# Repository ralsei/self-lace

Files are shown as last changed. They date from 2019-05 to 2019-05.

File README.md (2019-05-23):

# Self-lacing Shoe

My final project for Swartzendruber's Digital Electronics class in 2019, built w/ Skillet (https://github.com/killerskyman).
It's a shoe that ties itself.

## Render

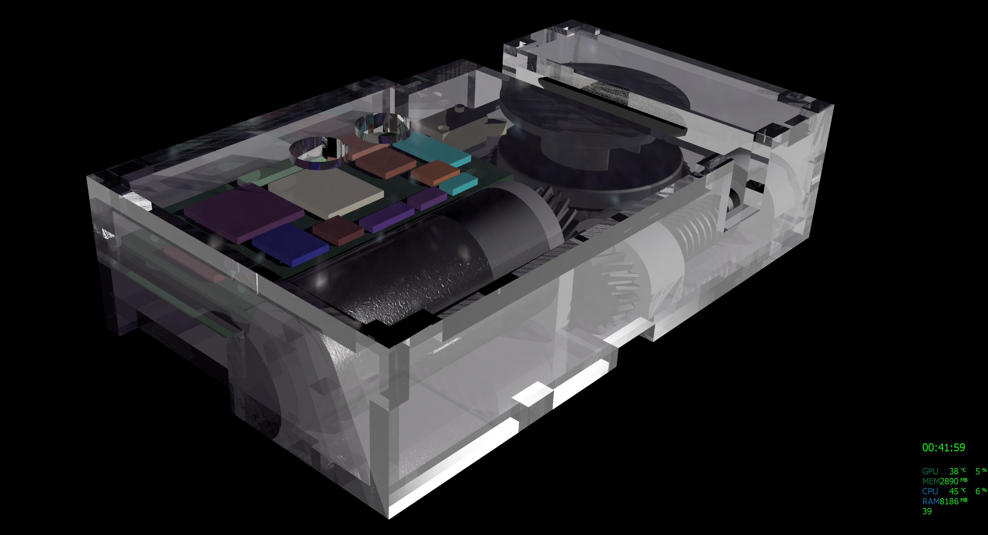
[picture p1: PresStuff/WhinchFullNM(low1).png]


## Licensing

It's under the BSD license with an additional clause stating that you can't use this for PLTW.

## Building

The CAD is made in Inventor, and the PCB is made in EAGLE.
To build the code, you must make the PCB as specified, bootload it, then upload code via FTDI.

Use the script `build` with the following parameters:

`./build main.ino <your TTY here>`

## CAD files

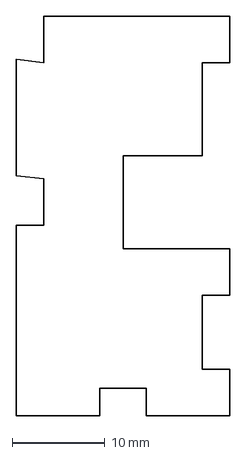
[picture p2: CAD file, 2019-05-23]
CAD/ShoeWinch/Laser/lefttopnm.dxf
23.0 x 43.0 mm

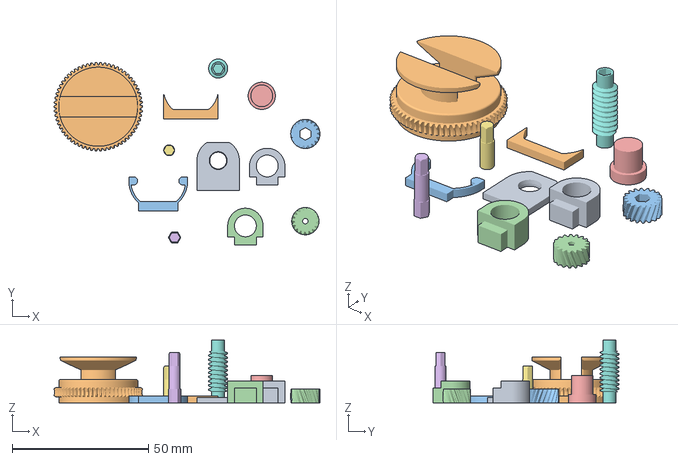
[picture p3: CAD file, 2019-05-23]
CAD/ShoeWinch/printer/Basecomp_Solid3_3.3mf
97.6 x 68.2 x 23.0 mm

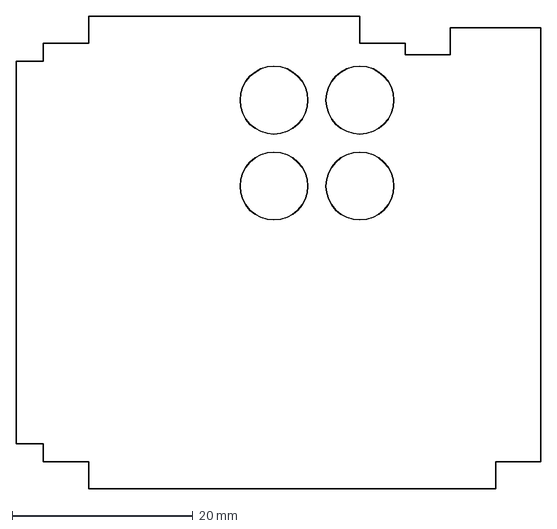
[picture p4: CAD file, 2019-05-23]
CAD/ShoeWinch/Laser/top.dxf
58.0 x 52.3 mm

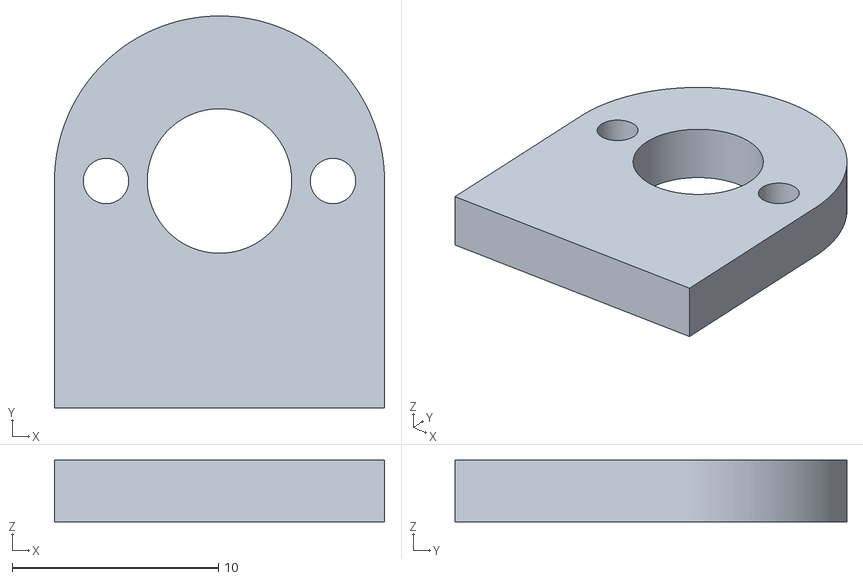
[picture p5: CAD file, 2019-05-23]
CAD/ShoeWinch/printer/PartsNM_MotorHolderNM_4.stl
16.0 x 19.0 x 3.00

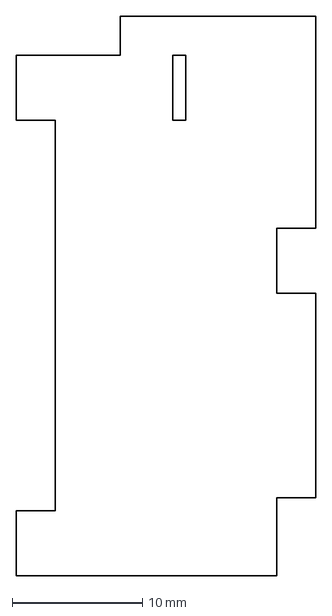
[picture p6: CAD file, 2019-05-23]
CAD/ShoeWinch/Laser/leftbot.dxf
23.1 x 43.0 mm

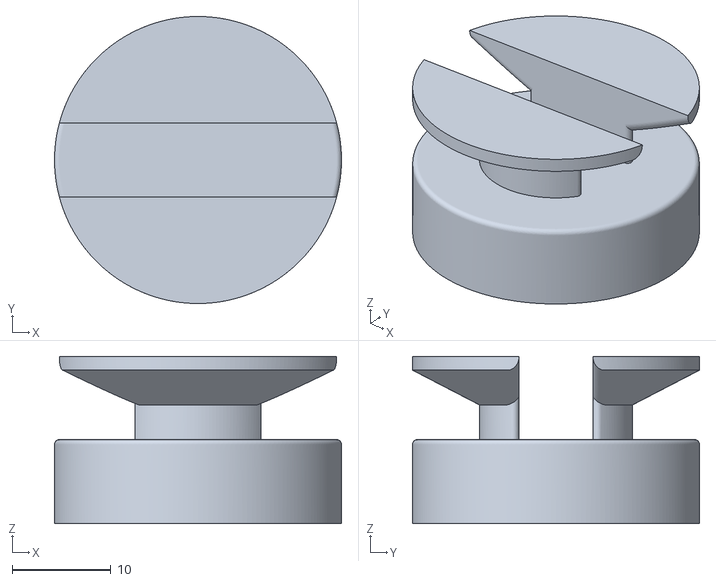
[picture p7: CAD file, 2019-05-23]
CAD/ShoeWinch/printer/WinchNM.stl
29.0 x 29.0 x 16.9

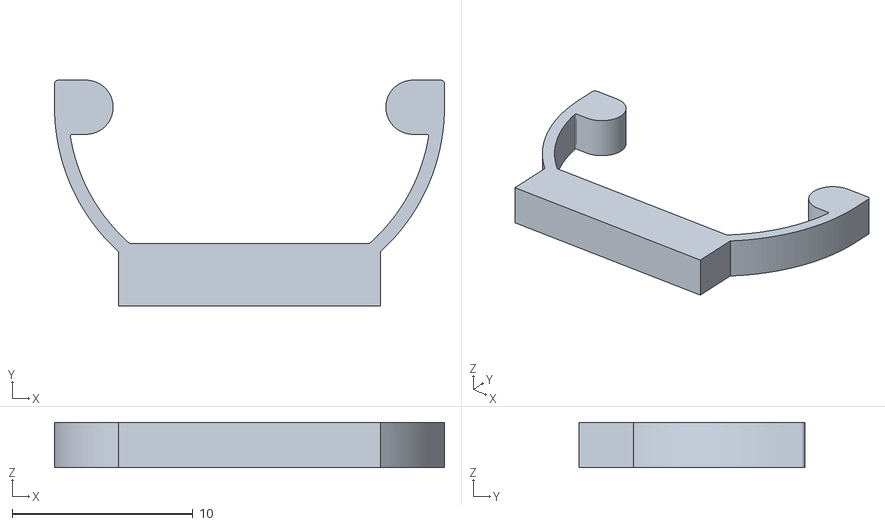
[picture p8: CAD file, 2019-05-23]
CAD/ShoeWinch/printer/Basecomp_Solid5_5.stl
21.6 x 12.5 x 2.50

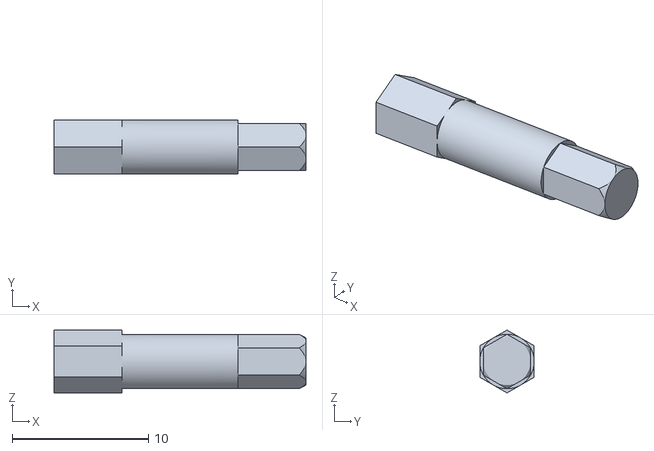
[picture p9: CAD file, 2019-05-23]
CAD/ShoeWinch/printer/Shaft2.stl
18.5 x 4.00 x 4.62

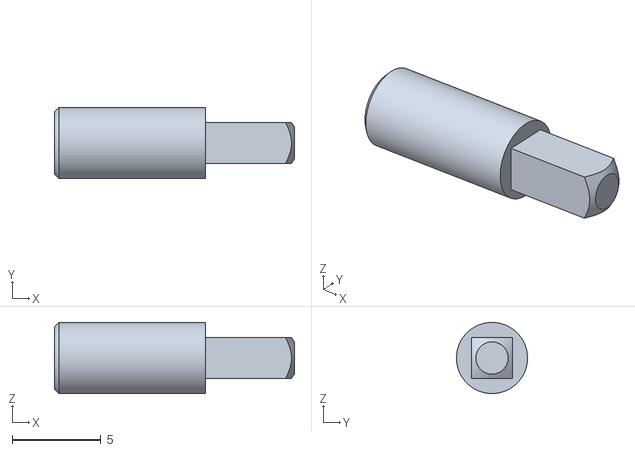
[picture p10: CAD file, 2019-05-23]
CAD/ShoeWinch/printer/Shaft3_2.stl
13.5 x 4.00 x 4.00

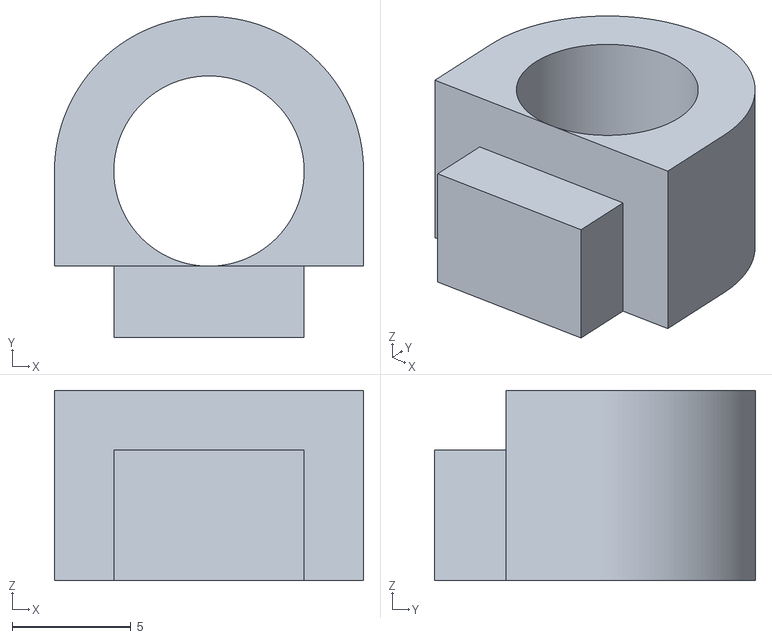
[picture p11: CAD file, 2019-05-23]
CAD/ShoeWinch/printer/Basecomp_Solid1_1.stl
13.0 x 13.5 x 8.00

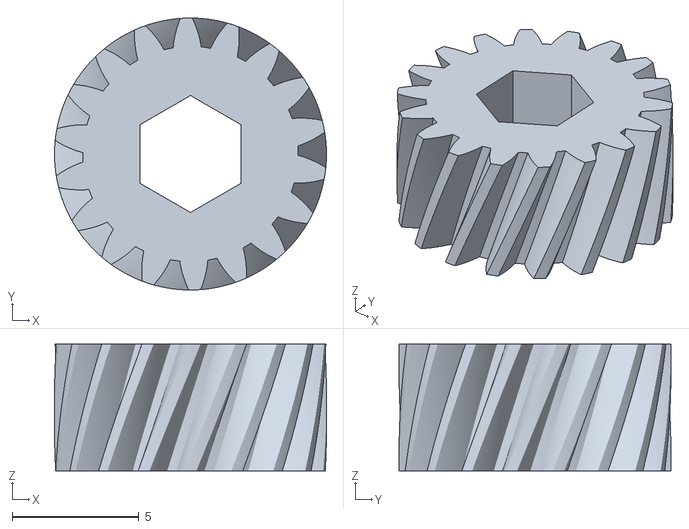
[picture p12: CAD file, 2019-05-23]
CAD/ShoeWinch/printer/Spur Gear21.stl
10.7 x 10.7 x 5.00

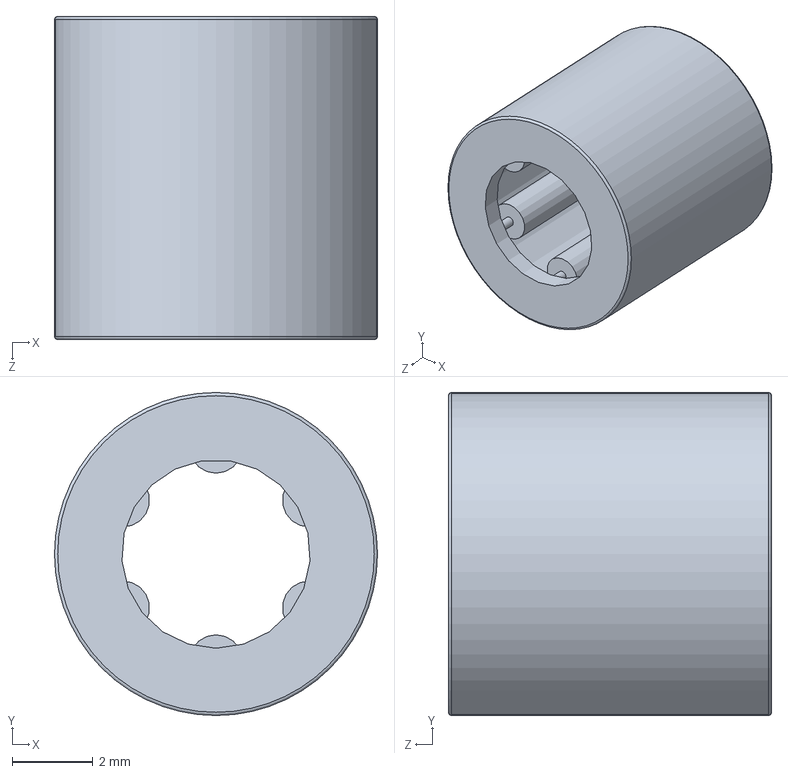
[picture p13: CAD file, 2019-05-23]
CAD/ShoeWinch/5905K348_STEEL NEEDLE-ROLLER BEARING.SLDPRT
7.99 x 7.99 x 8.00 mm

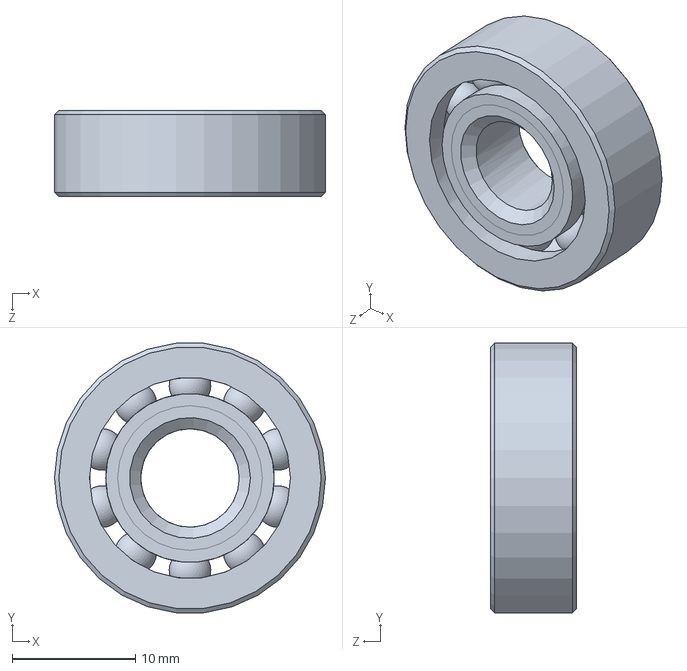
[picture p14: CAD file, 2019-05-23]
CAD/ShoeWinch/6455K440_GENERAL PURPOSE PLASTIC BALL BEARING.SLDPRT
22.0 x 21.9 x 7.00 mm

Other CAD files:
CAD/ShoeWinch/BaseNM.ipt
CAD/ShoeWinch/Basecomp.iam
CAD/ShoeWinch/Bearing(608).ipt
CAD/ShoeWinch/Bearing(8mm).ipt
CAD/ShoeWinch/BearingHolderLargeNM.ipt
CAD/ShoeWinch/BearingHolderNM.ipt
CAD/ShoeWinch/BearingHolderSmallMNM.ipt
CAD/ShoeWinch/BearingHolderSmallNM.ipt
CAD/ShoeWinch/CircuitBaseNM.ipt
CAD/ShoeWinch/LimitSwitch.ipt
CAD/ShoeWinch/MotorHolderBackNM.ipt
CAD/ShoeWinch/MotorHolderNM.ipt
CAD/ShoeWinch/MotorNM.ipt
CAD/ShoeWinch/Part2NM.ipt
CAD/ShoeWinch/Part3.ipt
CAD/ShoeWinch/PartsNM.iam
CAD/ShoeWinch/SideBottomNM.ipt
CAD/ShoeWinch/SideFaceBottomNM.ipt
CAD/ShoeWinch/SideFaceTopNM.ipt
CAD/ShoeWinch/SideLeftLower.ipt
CAD/ShoeWinch/SideLeftTopNM.ipt
CAD/ShoeWinch/SideRightNM.ipt
CAD/ShoeWinch/SideTopNM.ipt
CAD/ShoeWinch/WhinchFullNM.iam
CAD/ShoeWinch/WhinchFullNM.idw
CAD/ShoeWinch/WhinchFullNM.ipn
CAD/ShoeWinch/Winch/Design Accelerator/OldVersions/Shaft2.0005.iam
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

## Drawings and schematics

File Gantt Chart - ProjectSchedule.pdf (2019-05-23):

# SELF-LACING SHOES

### Swartzendruber G3

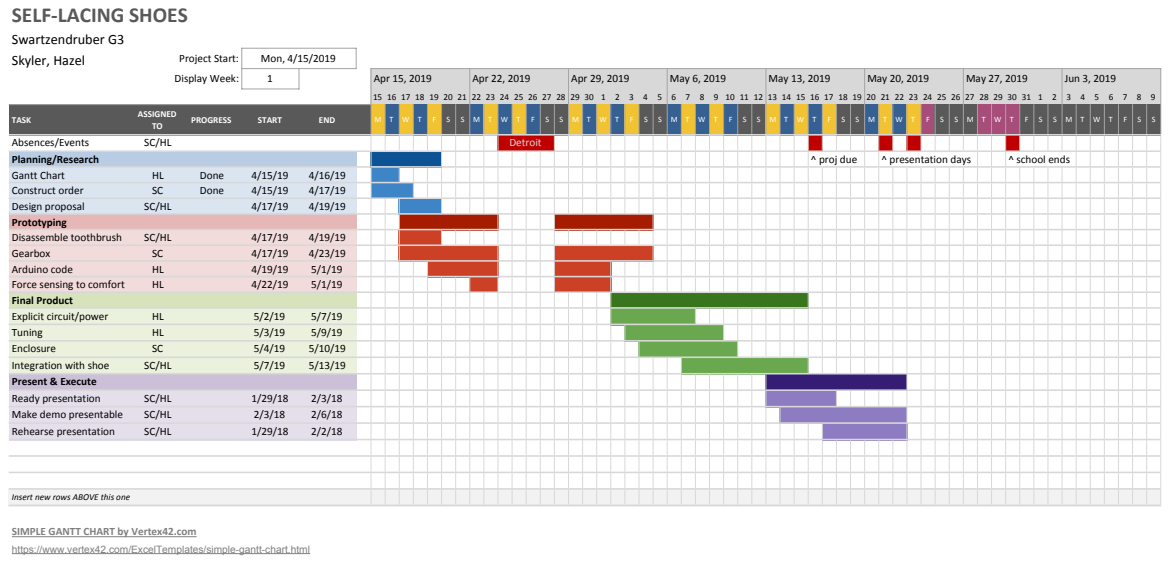
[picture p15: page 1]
Skyler, Hazel; Project Start:; Mon, 4/15/2019; Display Week:; Apr 15, 2019; Apr 22, 2019; Apr 29, 2019; May 6, 2019; May 13, 2019; May 20, 2019; May 27, 2019; Jun 3, 2019; TASK; ASSIGNED; PROGRESS; START; END; Absences/Events; Detroit; Planning/Research; ^ proj due; ^ presentation days; ^ school ends; Gantt Chart; Done; Construct order; Design proposal; Prototyping; Disassemble toothbrush; Gearbox; Arduino code; Force sensing to comfort; Final Product; Explicit circuit/power; Tuning; Enclosure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

Insert new rows ABOVE this one

https://www.vertex42.com/ExcelTemplates/simple-gantt-chart.html

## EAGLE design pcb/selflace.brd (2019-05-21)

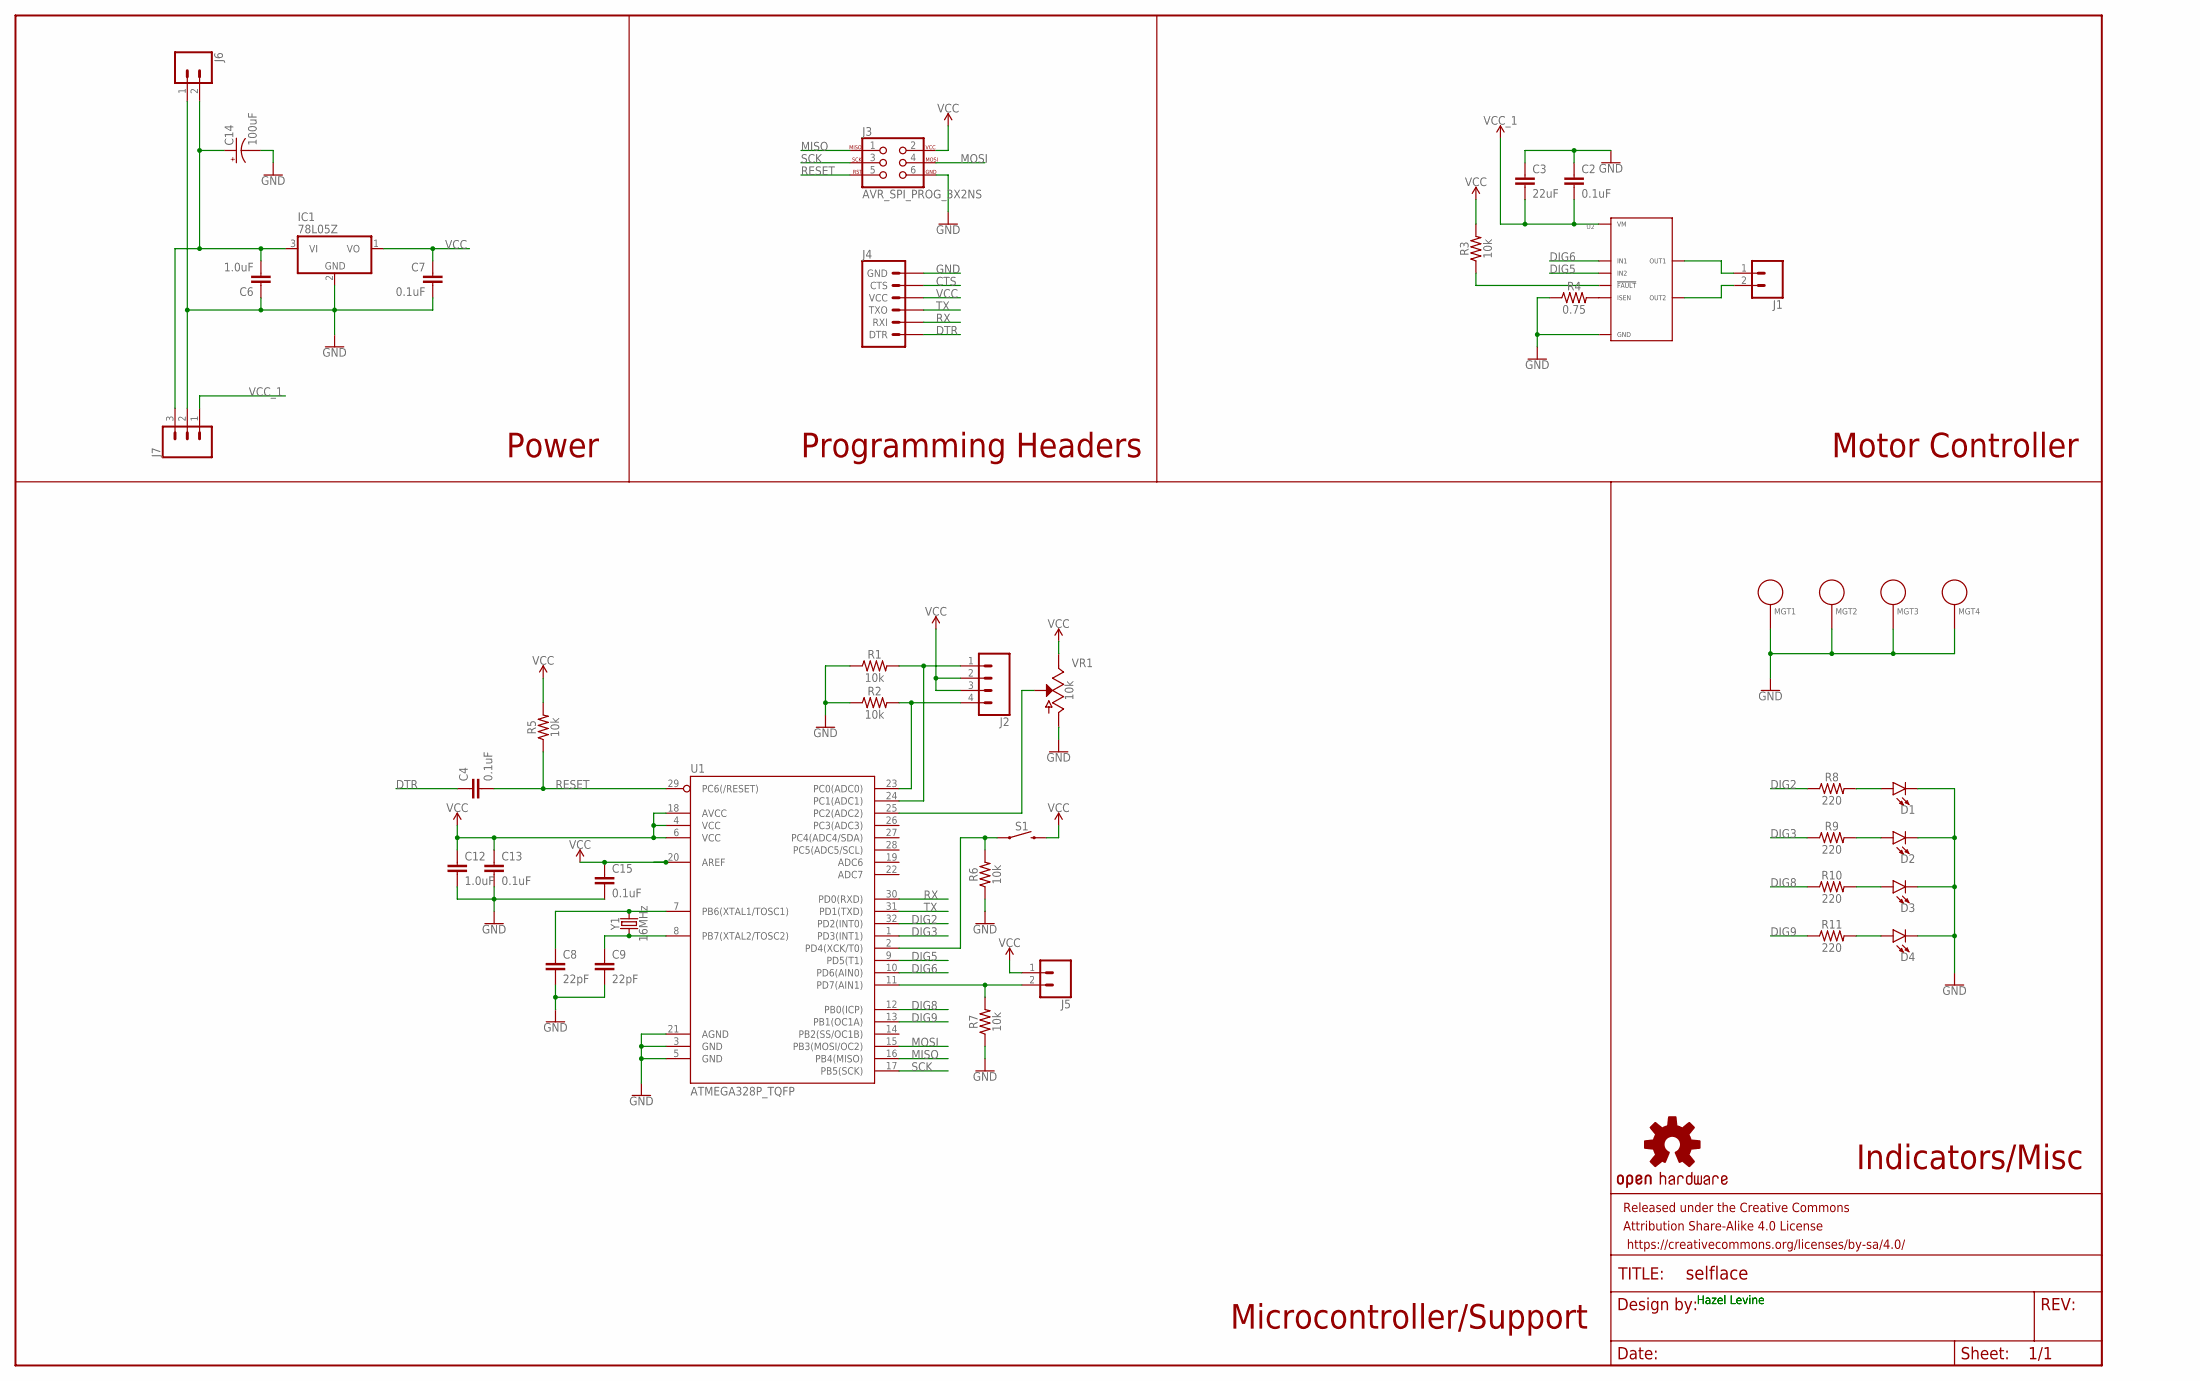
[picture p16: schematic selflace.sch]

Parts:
C2, C4, C7, C13, C15: 0.1uF; 0603
C3: 22uF; 0805
C6, C12: 1.0uF; 0603
C8, C9: 22pF; 0603
C14: 100uF; NIC_10X10.5_CAP
D1, D2, D3, D4: LED1206; LED-1206
FRAME1: FRAME-LEDGER; CREATIVE_COMMONS
IC1: 78L05Z; TO92
J1, J5: CONN_02; 1X02
J2: CONN_04; 1X04
J3: AVR_SPI_PROG_3X2NS; 2X3-NS
J4: 6_PIN_SERIAL_TARGETSILK; 6_PIN_SERIAL_TARGET_SIDE_W_SILK
J6: CONN_02JST-PTH-2; JST-2-PTH
J7: CONN_03; 1X03
LOGO1: OSHW-LOGOM; OSHW-LOGO-M
MGT1, MGT2, MGT3, MGT4: BEAGLEBONEBLACK_MOUNTING_HOLE
R1, R2, R3, R5, R6, R7: 10k; 0603
R4: 0.75; 0805
R8, R9, R10, R11: 220; 0603
S1: MOMENTARY-SWITCH-SPST-PTH-6.0MM; TACTILE_SWITCH_PTH_6.0MM
U1: ATMEGA328P_TQFP; TQFP32-08
U2: DRV8872DDARQ1; DRV8872_HSOP-8
VR1: 10k; POT-PTH-ALPS
Y1: 16MHz; CRYSTAL-SMD-5X3.2-4PAD

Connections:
CTS: J4.P$5 (CTS)
DIG2: R8.1, U1.32 (PD2(INT0))
DIG3: R9.1, U1.1 (PD3(INT1))
DIG5: U1.9 (PD5(T1)), U2.P$2 (IN2)
DIG6: U1.10 (PD6(AIN0)), U2.P$3 (IN1)
DIG8: R10.1, U1.12 (PB0(ICP))
DIG9: R11.1, U1.13 (PB1(OC1A))
DTR: C4.1, J4.P$1 (DTR)
GND: C2.1, C3.1, C6.1, C7.2, C8.2, C9.2, C12.2, C13.2, C14.-, C15.2, D1.C, D2.C, D3.C, D4.C, IC1.2 (GND), J3.6, J4.P$6 (GND), J6.1, J7.2, MGT1.P$1, MGT2.P$1, MGT3.P$1, MGT4.P$1, R1.1, R2.1, R4.1, R6.1, R7.1, U1.3 (GND), U1.5 (GND), U1.21 (AGND), U2.P$1 (GND), U2.P$9 (GND), U2.P$10 (GND), U2.P$11 (GND), U2.P$12 (GND), U2.P$13 (GND), U2.P$14 (GND), U2.P$15 (GND), VR1.P$3 (A)
MISO: J3.1, U1.16 (PB4(MISO))
MOSI: J3.4, U1.15 (PB3(MOSI/OC2))
unnamed: R6.2, S1.1, U1.2 (PD4(XCK/T0))
unnamed: J5.2, R7.2, U1.11 (PD7(AIN1))
unnamed: R3.1, U2.P$4 (!FAULT)
unnamed: J1.1, U2.P$6 (OUT1)
unnamed: J1.2, U2.P$8 (OUT2)
unnamed: U1.25 (PC2(ADC2)), VR1.P$2 (S)
unnamed: C8.1, U1.7 (PB6(XTAL1/TOSC1)), Y1.3 (2)
unnamed: R4.2, U2.P$7 (ISEN)
unnamed: J2.4, R2.2, U1.23 (PC0(ADC0))
unnamed: J2.1, R1.2, U1.24 (PC1(ADC1))
unnamed: C9.1, U1.8 (PB7(XTAL2/TOSC2)), Y1.1
unnamed: C6.2, C14.+, IC1.3 (VI), J6.2, J7.3
unnamed: D1.A, R8.2
unnamed: D2.A, R9.2
unnamed: D3.A, R10.2
unnamed: D4.A, R11.2
RESET: C4.2, J3.5, R5.1, U1.29 (PC6(/RESET))
RX: J4.P$3 (RXI), U1.30 (PD0(RXD))
SCK: J3.3, U1.17 (PB5(SCK))
TX: J4.P$2 (TXO), U1.31 (PD1(TXD))
VCC: C7.1, C12.1, C13.1, C15.1, IC1.1 (VO), J2.2, J2.3, J3.2, J4.P$4 (VCC), J5.1, R3.2, R5.2, S1.3 (2), U1.4 (VCC), U1.6 (VCC), U1.18 (AVCC), U1.20 (AREF), VR1.P$1 (E)
VCC_1: C2.2, C3.2, J7.1, U2.P$5 (VM)

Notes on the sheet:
Hazel Levine
Power
Microcontroller/Support
Programming Headers
Motor Controller
Indicators/Misc

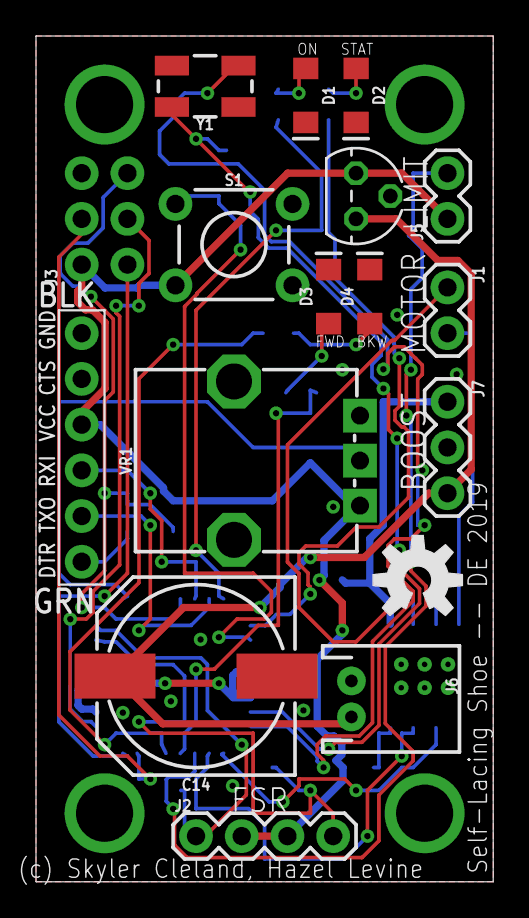
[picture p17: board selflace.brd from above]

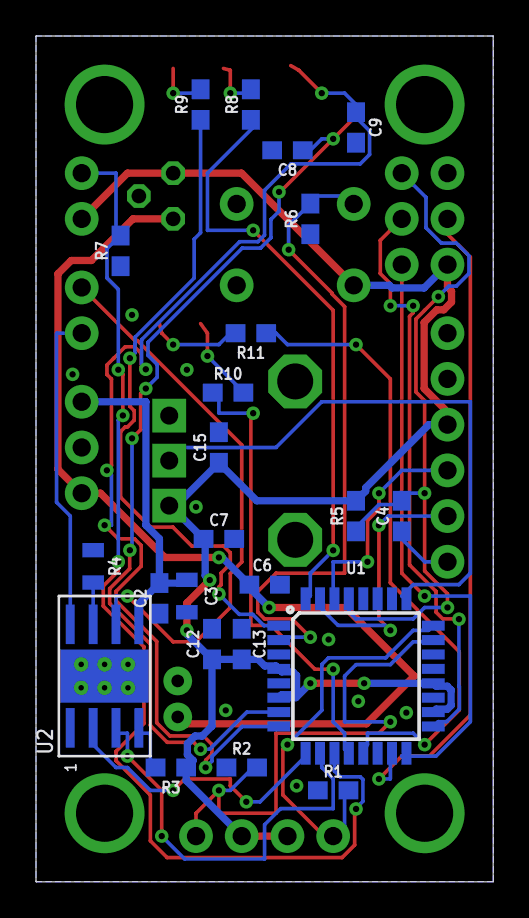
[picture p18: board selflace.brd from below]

Board: 2 copper layers, 25.4 x 47.0 mm, 45 parts (23 on the bottom side), 32 nets.

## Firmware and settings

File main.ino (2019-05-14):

#include <AutoPID.h>

/// PIN DEFINITIONS
const int FSR_F_PIN = A0; // the actual force sensor
const int FSR_S_PIN = A1; // is there a shoe?
const int POT_PIN = A2;   // change force

const int MOTOR_1A_PIN = 5; // hbridge leg 1
const int MOTOR_2A_PIN = 6; // hbridge leg 2
const int RELEASE_PIN = 4;
const int LIMIT_PIN = 7;

const int LED_ON_PIN = 2;
const int LED_STAT_PIN = 3;
const int LED_FWD_PIN = 8;
const int LED_BKW_PIN = 9;

/// GLOBAL STATES
bool output = false;
bool wasPressed = false;
bool relayState = false;

/// PID 
const int Kp = 1, Ki = 0, Kd = 0;
double m_setpoint, m_input, m_output;
AutoPID m_control{&m_input, &m_setpoint, &m_output, -255, 255, Kp, Ki, Kd};

void motorCtrl_write(int val) { // set motor controller to given power
  if (val > 0) {
    analogWrite(MOTOR_1A_PIN, val);
    analogWrite(MOTOR_2A_PIN, 0);

    digitalWrite(LED_FWD_PIN, HIGH);
    digitalWrite(LED_BKW_PIN, LOW);
  } else if (val < 0) {
    analogWrite(MOTOR_2A_PIN, -val);
    analogWrite(MOTOR_1A_PIN, 0);

    digitalWrite(LED_FWD_PIN, LOW);
    digitalWrite(LED_BKW_PIN, HIGH);
  } else {
    analogWrite(MOTOR_1A_PIN, 0);
    analogWrite(MOTOR_2A_PIN, 0);

    digitalWrite(LED_FWD_PIN, LOW);
    digitalWrite(LED_BKW_PIN, LOW);
  }
}

bool fsr_isDetected() { // is the bottom FSR detecting a human?
  return (analogRead(FSR_S_PIN) > 100); // threshold for mg
}

int fsr_getAnalog() { // returns the raw value of the force FSR
  return analogRead(FSR_F_PIN);
}

int fsr_getNewtons() { // "should" (RFC 2119) return the FSR value in Newtons
  int fsrVoltage = map(fsr_getAnalog(), 0, 1023, 0, 5000); // 0-1023 to 0-5V (5000 mV)
  long fsrForce;

  if (fsrVoltage == 0) {
    return 0; // no net force on the sensor
  } else {
    // the voltage = vcc * R / (R + FSR) where R = 10K and Vcc = 5V
    // so FSR = ((Vcc - V) * R) / V
    unsigned long fsrResistance = 5000 - fsrVoltage;
    fsrResistance *= 10000;
    fsrResistance /= fsrVoltage;

    unsigned long fsrConductance = 1000000; // microMhos
    fsrConductance /= fsrResistance;

    // fsr graphs from datasheet: https://cdn-shop.adafruit.com/datasheets/FSR400Series_PD.pdf
    if (fsrConductance <= 1000) {
      fsrForce = fsrConductance / 80;
    } else {
      fsrForce = fsrConductance - 1000;
      fsrForce /= 30;
    }
  }

  return fsrForce;
}

int pot_getAnalog() {
  return analogRead(POT_PIN);
}

int pot_getSetpoint() {
  return map(pot_getAnalog(), 0, 1023, 0, 50); // last value is threshold
}

void setup() {
  pinMode(MOTOR_1A_PIN, OUTPUT);
  pinMode(MOTOR_2A_PIN, OUTPUT);

  pinMode(LED_ON_PIN, OUTPUT);
  pinMode(LED_STAT_PIN, OUTPUT);
  pinMode(LED_FWD_PIN, OUTPUT);
  pinMode(LED_BKW_PIN, OUTPUT);

  m_input = fsr_getNewtons();
  m_setpoint = 15; // default
  
  Serial.begin(9600);
  m_control.setTimeStep(50);
}

void loop() {
  digitalWrite(LED_ON_PIN, HIGH);

  m_input = fsr_getAnalog();
  m_setpoint = pot_getAnalog();

  if (fsr_isDetected()) {
    output = true;
  }
  
  if (digitalRead(RELEASE_PIN)) {
    if (!wasPressed){
      output = !output;
      m_output = -255;
    }
    wasPressed = true;
  } else {
    wasPressed = false;
  }

  if (digitalRead(LIMIT_PIN) == 1) {
    output = false;
    m_output = 0;
  }

  if (output) {
    m_control.run();
  }
  motorCtrl_write(m_output);

  Serial.print("FSR value (N): ");
  Serial.print(m_input);
  Serial.print("Attempted output: ");
  Serial.print(m_output);
  Serial.print("Pot value: ");
  Serial.println(pot_getAnalog());
  delay(100); // i have no clue why this works. but it does. so leave me alone...
              // also it helps with serial debug... i guess...
}

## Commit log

2019-05-09 fix pcb, rewrite build script, move main
    [selflace.brd, selflace.sch]
2019-05-10 sending sch off for review
    [selflace.brd, selflace.sch]
2019-05-10 maybe finish schematic, sending off for review
    [selflace.brd, selflace.sch]
2019-05-11 nearly done! sending off for final review
    [selflace.brd, selflace.sch]
2019-05-12 add LEDs
    [selflace.brd]
2019-05-12 update board to size specs and increase power/ground trace width
    [selflace.brd, selflace.sch]
2019-05-12 add sch border back, fix wire stubs
    [selflace.brd, selflace.sch]
2019-05-12 fix some more wire stubs
    [selflace.brd]
2019-05-12 fix a thin ground trace
    [selflace.brd]
2019-05-12 routing is hell and i hate it
    [selflace.brd, selflace.sch]
2019-05-12 yay, it's a thing that does a thing that's made to do a thing
    [selflace.brd]
2019-05-13 maybe final
    [selflace.brd]
2019-05-21 Revert "instead of running indefinitely, set m_setpoint to 0 on ul"
    This reverts commit d9a936486a13b2ac75d62348d48fa9a448d22195.
    [main.ino]
2019-05-21 fix rx/tx, not present on in-class pcb
    [selflace.brd, selflace.sch]
2019-05-23 cad commit
    [5905K348_STEEL NEEDLE-ROLLER BEARING.SLDPRT, 6455K440_GENERAL PURPOSE PLASTIC BALL BEARING.SLDPRT, BaseNM.ipt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]

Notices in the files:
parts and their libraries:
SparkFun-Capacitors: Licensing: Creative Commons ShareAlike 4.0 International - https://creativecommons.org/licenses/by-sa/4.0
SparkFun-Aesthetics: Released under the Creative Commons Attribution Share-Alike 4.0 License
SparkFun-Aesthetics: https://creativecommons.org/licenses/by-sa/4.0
